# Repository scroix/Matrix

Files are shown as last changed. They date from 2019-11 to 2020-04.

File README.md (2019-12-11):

# eTextile matrix sensor / V1.0 Extension board with builtin Teensy 3.2
### Transforming textiles into an intuitive way to interact with computers
#### This project is part of an electronic textiles research on HCI gesture interaction that was started in 2005

- Author: Maurin Donneaud <maurin@etextile.org>
- Repository: https://github.com/eTextile/Matrix/tree/teensy_matrix
- Project web page: http://matrix.eTextile.org
- License: CC-BY-SA (see the License file)



## About The project
Using a fabric to sense the touch is now possible with the E256 eTextile matrix sensor.
The E256 is a development kit for designers, makers and companies who want to combine textile and programing into new eTextile projects. From the beginning this project stimulates the development of technologies in artistic use cases: playing music, combine graphics and sound, creating textile furniture that can have tactile properties, etc, etc.

This kit features 30cm by 30cm sensitive textile that allow multi-touch sensing and pressures topographic analysis.
The software, frmware and hardware are distributed under Creative Commons license (Cf: LICENSE.txt). The E256 firmware is made with Arduino IDE. BLE hardware is the next step to interface the E256-textile with mobile devices. Made out of conductive textile shaped in rows and columns and a layer of piezoresistive fabric, the E256-textile sensor is designed to be easy to make.

## Project content
- Arduino firmware : Teensy 3.1, 3.2, 4.0(TODO)
- PCB made with [KiCad](https://kicad-pcb.org/)
- eTextile matrix sensor HOWTO
- Real time 3D visualization using [openFrameworks](https://www.openframeworks.cc/)
- Audio players running on Raspberry and Bela-mini using [libPd](https://github.com/libpd)
- Same players can be lodded on PC with PureData Vanilla (http://msp.ucsd.edu/software.html)

## Publications
- [NIME17](http://www.nime2017.org/) - Designing a Multi-Touch eTextile for Music Performances.
- Maurin Donneaud, Cedric Honnet, Paul Strohmeier
  - [Paper](https://etextile.github.io/resistiveMatrix/publications/NIME17-eTextile.pdf) - [Video](https://vimeo.com/217690743)
- [MOCO17](http://moco17.movementcomputing.org/) - Music Skin: Fabric Interface for Expressive Music Control.
- Maurin Donneaud, Cedric Honnet, Paul Strohmeier
  - [Paper](https://etextile.github.io/resistiveMatrix/publications/MOCO17-MusicSkin.pdf)

## Docs
- [A video made at Schmiede 2014](http://www.kobakant.at/DIY/?p=4305/)
- [Pictures of the project and context](https://www.flickr.com/photos/maurin/albums/72157673740361510)

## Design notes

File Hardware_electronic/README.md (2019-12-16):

# eTextile matrix sensor
### Transforming textiles into an intuitive way to interact with computers
#### This project is part of an electronic textiles research on HCI gesture interaction that was started in 2005

- Author: Maurin Donneaud <maurin@etextile.org>
- Repository: https://github.com/eTextile/Matrix/tree/teensy_matrix
- Project web page: http://matrix.eTextile.org
- License: CC-BY-SA (see the License file)

### Eagle
V1.0 : the Eagle file contain a PCB with eTextile-bus solution (not available as market product)

### KiCad
V2.0 : the KiCad file contain a PCB that avoid the need of eTextile-bus

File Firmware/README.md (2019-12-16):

# E256-S / Arduino / Firmaware

### Transforming textiles into an intuitive way to interact with computers
### This project is part of an electronic textiles research on HCI gesture interaction that was started in 2005

- Author: Maurin Donneaud <maurin@etextile.org>
- Repository: https://github.com/eTextile/Matrix/tree/teensy_matrix
- Project web page: www.eTextile.org
- License: CC-BY-SA (see the License file)



## Requirements
- Programed with Arduino IDE
- This Arduino Sketch require:
 - ...

### Settings for Arduino IDE
- Board:	 Teensy_3.2 / 4.0
- USB Type:  Serial

## Program Synopsis

## Data Transmission

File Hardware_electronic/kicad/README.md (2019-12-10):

# eTextile matrix sensor
### Transforming textiles into an intuitive way to interact with computers
#### This project is part of an electronic textiles research on HCI gesture interaction that was started in 2005

- Author: Maurin Donneaud <maurin@etextile.org>
- Repository: https://github.com/eTextile/Matrix/tree/teensy_matrix
- Project web page: http://matrix.eTextile.org
- License: CC-BY-SA (see the License file)

### Eagle
This file is contanoing a PCB with eTextile bus connector - V1

### KiCad 
the textile bus systhem is not a maket productso I switch to the - V2

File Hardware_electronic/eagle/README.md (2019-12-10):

# eTextile matrix sensor / PCB

### Transforming textiles into an intuitive way to interact with computers
#### This project is part of an electronic textiles research on HCI gesture interaction that was started in 2005

- Author: Maurin Donneaud <maurin@etextile.org>
- Repository: https://github.com/eTextile/Matrix/tree/teensy_matrix
- Project web page: https://matrix.eTextile.org
- License: CC-BY-SA (see the License file)

This PCB is designed for a custom eTextile connection between a textile matrix and the Teensy_3.2 microcontroller I/O pins.

## Partslist

| Part | Value | Device | Package |
|---|:---|:---|:---|
ANALOG_INPUT  | 3.3V                         | PINHD-1X16/90           | 1X16/90              |
ANALOG_INPUT1 | 3.3V                         | PINHD-1X16              | 1X16                 |
C1            | 4.7uF                        | CAP0805                 | 0805                 |
C2            | 4.7uF                        | CAP0805                 | 0805                 |
C3            | 10uf                         | CPOL-EUE1.8-4           | E1,8-4               |
D1            | RED                          | LED1206                 | LED-1206             |
D11           | RED                          | LED1206                 | LED-1206             |
DIGITAL_OUT   |                              | PINHD-1X16/90           | 1X16/90              |
DIGITAL_OUT1  | 3.3V                         | PINHD-1X16/90           | 1X16/90              |
JP7           | LiPo Battery                 | M02-JST-2MM-SMT         | JST-2-SMD            |
R1            | 2K                           | RESISTOR0805-RES        | 0805                 |
R2            | 330                          | RESISTOR0805-RES        | 0805                 |
R3            | 330                          | RESISTOR0805-RES        | 0805                 |
RN1           | 3.3V                         | G08R                    | SIL9                 |
RN2           | 3.3V                         | G08R                    | SIL9                 |
S1            | SWITCH                       | SWITCH-SPSTSMD          | AYZ0202              |
SWITCH1       | SWITCH-MOMENTARY-2           | SWITCH-MOMENTARY-2      | TACTILE_SWITCH_TALL  |
U$1           | TEENSY_3.1_ALL_PINS_AND_PADS | TEENSY_3.1_ALL_PINS_AND_PADS | TEENSY_3.1_ALLPINS   |
U1            | MCP73831                     | MCP73831                     | SOT23-5              |
U3            |                              | AUDIO-JACKSMD2               | AUDIO-JACK-3.5MM-SMD |

## TODO

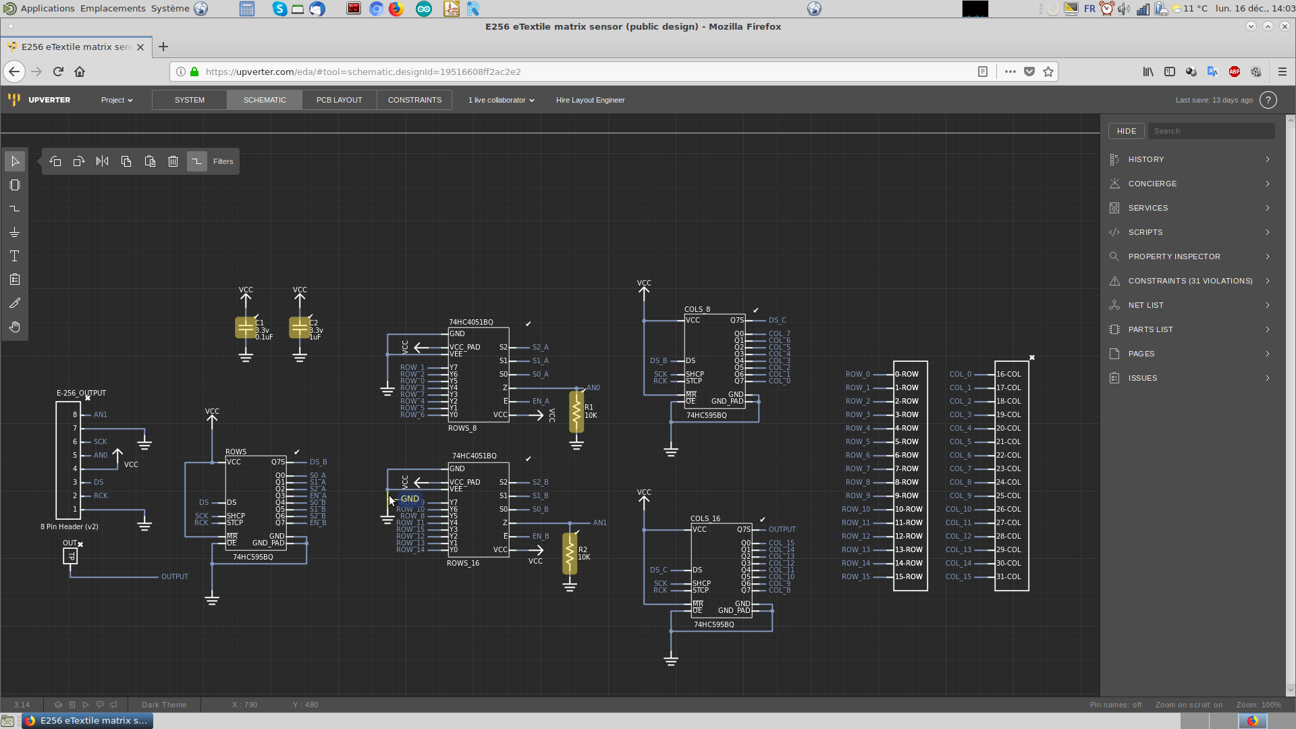
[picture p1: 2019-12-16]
Hardware_electronic/Capture du 2019-12-16 14-03-28.png

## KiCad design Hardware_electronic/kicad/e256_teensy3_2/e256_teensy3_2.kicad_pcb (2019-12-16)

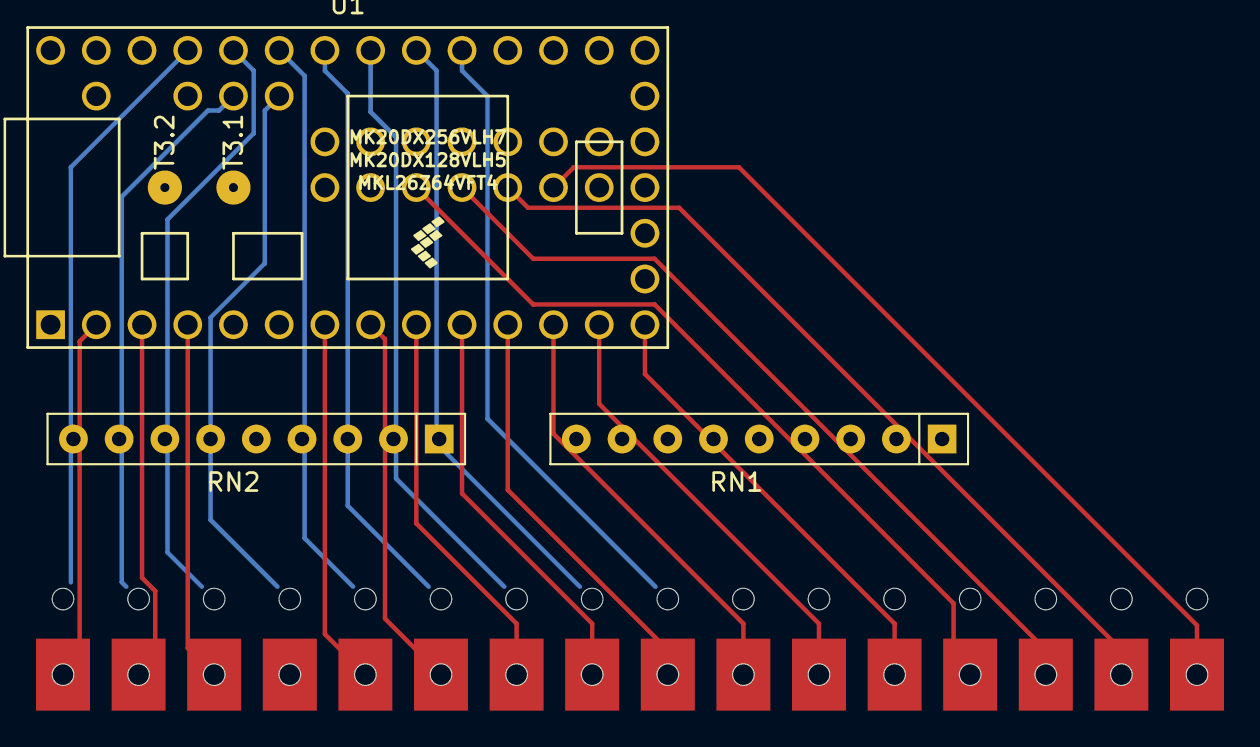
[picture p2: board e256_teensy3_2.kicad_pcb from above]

Board: 2 copper layers, 4 parts (0 on the bottom side), 31 nets.

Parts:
RN1, RN2: R_Network08_US; R_Array_SIP9
U1: Teensy3.2; Teensy30_31_32_LC
U2: e256_pad_16x16; e256_pad_16X16

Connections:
COL_0: RN1.2, U1.46, U2.16
COL_1: RN1.3, U1.47, U2.17
COL_2: RN1.4, U1.48, U2.18
COL_3: RN1.5, U1.49, U2.19
COL_4: RN1.6, U1.14, U2.20
COL_5: RN1.7, U1.13, U2.21
COL_6: RN1.8, U1.12, U2.22
COL_7: RN1.9, U1.11, U2.23
COL_8: RN2.2, U1.10, U2.24
COL_9: RN2.3, U1.9, U2.25
COL_10: RN2.4, U1.8, U2.26
COL_11: RN2.5, U1.7, U2.27
COL_12: RN2.6, U1.40, U2.28
COL_13: RN2.7, U1.4, U2.29
COL_14: RN2.8, U1.3, U2.30
COL_15: RN2.9, U1.2, U2.31
GNDREF: RN1.1, RN2.1, U1.1
ROW_0: U1.45, U2.0
ROW_1: U1.44, U2.1
ROW_2: U1.43, U2.2
ROW_3: U1.21, U2.3
ROW_4: U1.42, U2.4
ROW_5: U1.22, U2.5
ROW_6: U1.23, U2.6
ROW_7: U1.24, U2.7
ROW_10: U1.27, U2.10
ROW_11: U1.28, U2.11
ROW_12: U1.37, U2.12
ROW_13: U1.29, U2.13
ROW_14: U1.36, U2.14
ROW_15: U1.30, U2.15

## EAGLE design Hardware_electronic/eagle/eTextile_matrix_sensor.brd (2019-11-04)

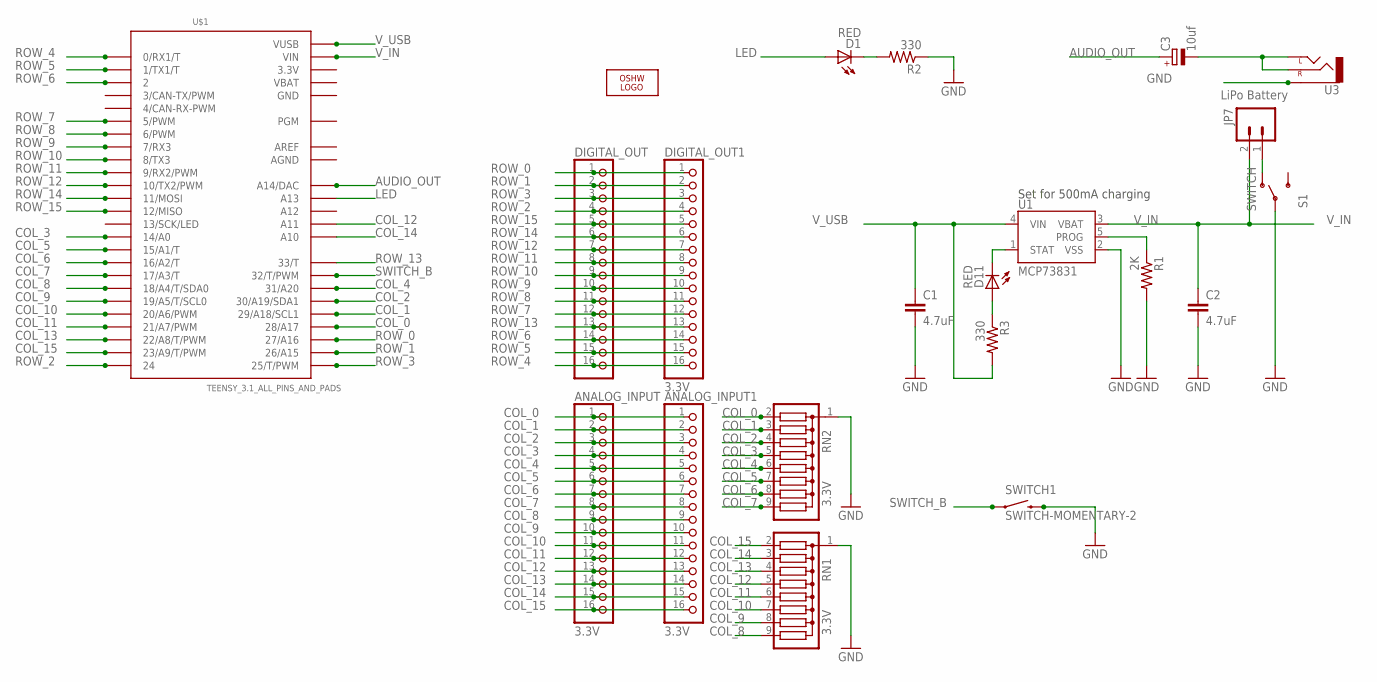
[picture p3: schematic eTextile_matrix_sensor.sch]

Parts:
ANALOG_INPUT: 3.3V; 1X16/90
ANALOG_INPUT1: 3.3V; 1X16
C1, C2: 4.7uF; 0805
C3: 10uf; E1,8-4
D1, D11: RED; LED-1206
DIGITAL_OUT: PINHD-1X16/90; 1X16/90
DIGITAL_OUT1: 3.3V; 1X16/90
JP7: LiPo Battery; JST-2-SMD
LOGO1: OSHW_LOGO_8MILX0350-NT; OSHW_8X350_NOTEXT
R1: 2K; 0805
R2, R3: 330; 0805
RN1, RN2: 3.3V; SIL9
S1: SWITCH; AYZ0202
SWITCH1: SWITCH-MOMENTARY-2; TACTILE_SWITCH_TALL
U1: MCP73831; SOT23-5
U3: AUDIO-JACKSMD2; AUDIO-JACK-3.5MM-SMD
U$1: TEENSY_3.1_ALL_PINS_AND_PADS; TEENSY_3.1_ALLPINS

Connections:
3.3V: U$1.3.3V, U$1.3.3V1 (3.3V), U$1.3.3V2 (3.3V)
AGND: U$1.AGND
AREF: U$1.AREF
AUDIO_OUT: C3.+, U$1.A14 (A14/DAC)
COL_0: ANALOG_INPUT.1, ANALOG_INPUT1.1, RN2.2, U$1.28 (28/A17)
COL_1: ANALOG_INPUT.2, ANALOG_INPUT1.2, RN2.3, U$1.29 (29/A18/SCL1)
COL_2: ANALOG_INPUT.3, ANALOG_INPUT1.3, RN2.4, U$1.30 (30/A19/SDA1)
COL_3: ANALOG_INPUT.4, ANALOG_INPUT1.4, RN2.5, U$1.14/A0
COL_4: ANALOG_INPUT.5, ANALOG_INPUT1.5, RN2.6, U$1.31 (31/A20)
COL_5: ANALOG_INPUT.6, ANALOG_INPUT1.6, RN2.7, U$1.15/A1 (15/A1/T)
COL_6: ANALOG_INPUT.7, ANALOG_INPUT1.7, RN2.8, U$1.16/A2 (16/A2/T)
COL_7: ANALOG_INPUT.8, ANALOG_INPUT1.8, RN2.9, U$1.17/A3 (17/A3/T)
COL_8: ANALOG_INPUT.9, ANALOG_INPUT1.9, RN1.9, U$1.18/A4 (18/A4/T/SDA0)
COL_9: ANALOG_INPUT.10, ANALOG_INPUT1.10, RN1.8, U$1.19/A5 (19/A5/T/SCL0)
COL_10: ANALOG_INPUT.11, ANALOG_INPUT1.11, RN1.7, U$1.20/A6 (20/A6/PWM)
COL_11: ANALOG_INPUT.12, ANALOG_INPUT1.12, RN1.6, U$1.21/A7 (21/A7/PWM)
COL_12: ANALOG_INPUT.13, ANALOG_INPUT1.13, RN1.5, U$1.A11
COL_13: ANALOG_INPUT.14, ANALOG_INPUT1.14, RN1.4, U$1.22/A8 (22/A8/T/PWM)
COL_14: ANALOG_INPUT.15, ANALOG_INPUT1.15, RN1.3, U$1.A10
COL_15: ANALOG_INPUT.16, ANALOG_INPUT1.16, RN1.2, U$1.23/A9 (23/A9/T/PWM)
GND: C1.2, C2.2, R1.2, R2.1, RN1.1, RN2.1, S1.2, SWITCH1.B2 (2), U1.2 (VSS), U3.SLEEVE, U$1.GND, U$1.GND1 (GND), U$1.GND2 (GND)
LED: D1.A, U$1.A13
unnamed: C3.-, U3.RING (RIGHT), U3.TIP (LEFT)
unnamed: D11.A, R3.1
unnamed: JP7.1, S1.1 (O)
unnamed: D1.C, R2.2
PROG: R1.1, U1.5 (PROG)
ROW_0: DIGITAL_OUT.1, DIGITAL_OUT1.1, U$1.27 (27/A16)
ROW_1: DIGITAL_OUT.2, DIGITAL_OUT1.2, U$1.26 (26/A15)
ROW_2: DIGITAL_OUT.4, DIGITAL_OUT1.4, U$1.24
ROW_3: DIGITAL_OUT.3, DIGITAL_OUT1.3, U$1.25 (25/T/PWM)
ROW_4: DIGITAL_OUT.16, DIGITAL_OUT1.16, U$1.0 (0/RX1/T)
ROW_5: DIGITAL_OUT.15, DIGITAL_OUT1.15, U$1.1 (1/TX1/T)
ROW_6: DIGITAL_OUT.14, DIGITAL_OUT1.14, U$1.2
ROW_7: DIGITAL_OUT.12, DIGITAL_OUT1.12, U$1.5 (5/PWM)
ROW_8: DIGITAL_OUT.11, DIGITAL_OUT1.11, U$1.6 (6/PWM)
ROW_9: DIGITAL_OUT.10, DIGITAL_OUT1.10, U$1.7 (7/RX3)
ROW_10: DIGITAL_OUT.9, DIGITAL_OUT1.9, U$1.8 (8/TX3)
ROW_11: DIGITAL_OUT.8, DIGITAL_OUT1.8, U$1.9 (9/RX2/PWM)
ROW_12: DIGITAL_OUT.7, DIGITAL_OUT1.7, U$1.10 (10/TX2/PWM)
ROW_13: DIGITAL_OUT.13, DIGITAL_OUT1.13, U$1.33 (33/T)
ROW_14: DIGITAL_OUT.6, DIGITAL_OUT1.6, U$1.11 (11/MOSI)
ROW_15: DIGITAL_OUT.5, DIGITAL_OUT1.5, U$1.12 (12/MISO)
STAT: D11.C, U1.1 (STAT)
SWITCH_B: SWITCH1.A2 (1), U$1.32 (32/T/PWM)
VBAT: U$1.VBAT
V_IN: C2.1, JP7.2, U1.3 (VBAT), U$1.VIN
V_USB: C1.1, R3.2, U1.4 (VIN), U$1.VUSB

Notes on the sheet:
Set for 500mA charging

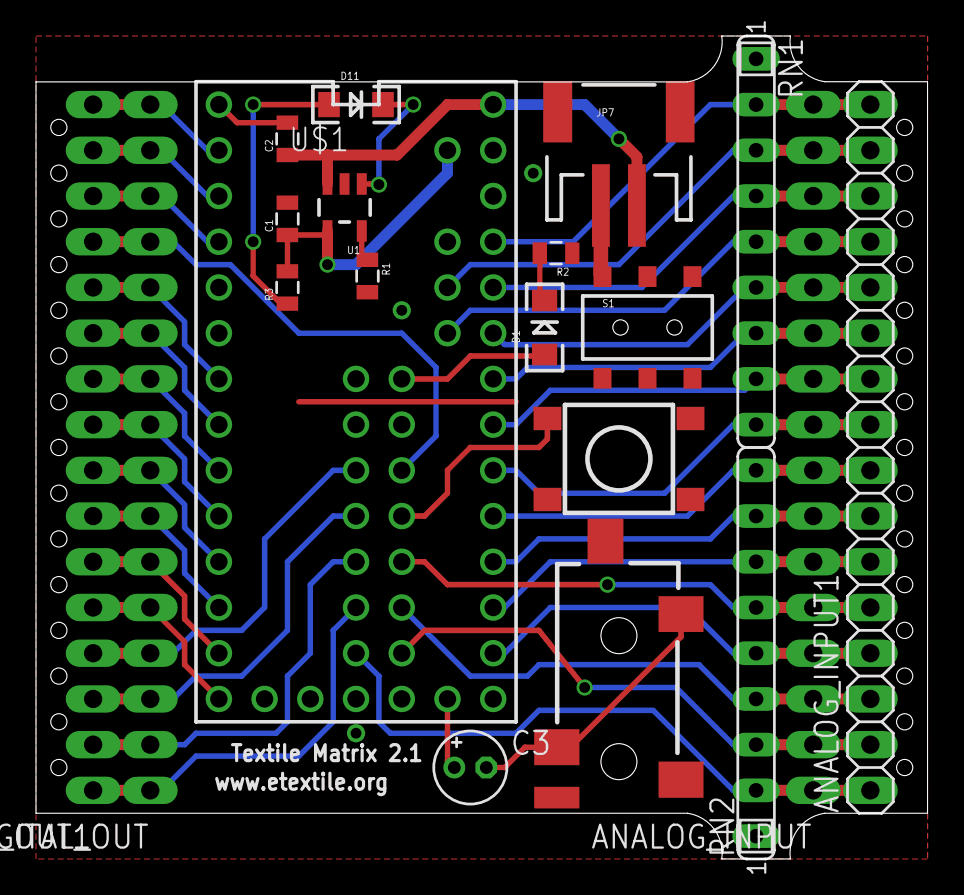
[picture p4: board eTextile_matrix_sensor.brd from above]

Board: 2 copper layers, 49.5 x 45.7 mm, 21 parts (0 on the bottom side), 45 nets.

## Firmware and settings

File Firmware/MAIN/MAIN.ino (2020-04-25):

/*
  ** E256 Firmware v1.1 **
  This file is part of the eTextile-matrix-sensor project - http://matrix.eTextile.org
  Copyright (c) 2014- Maurin Donneaud <maurin@etextile.org>
  This work is licensed under Creative Commons Attribution-ShareAlike 4.0 International license, see the LICENSE file for details.
*/

// FPS with CPU speed to 120 MHz (Overclock)
// Optimize Fastest with LTO (Link Time Optimizations)
//   523 FPS : ADC_INPUT
//    .. FPS : ADC_INPUT / BLOB_TRACKING
//    .. FPS : ADC_INPUT / BILINEAR_INTERPOLATION
//    39 FPS : ADC_INPUT / BILINEAR_INTERPOLATION / BLOB_TRACKING

#include <SPI.h>        // https://www.pjrc.com/teensy/td_libs_SPI.html
#include <ADC.h>        // https://github.com/pedvide/ADC
#include <MIDI.h>       // http://www.pjrc.com/teensy/td_midi.html

#include "config.h"
#include "interp.h"
#include "blob.h"

SPISettings settings(16000000, MSBFIRST, SPI_MODE0);

ADC *adc = new ADC();     // ADC object
ADC::Sync_result result;  // ADC_0 & ADC_1

// Array to store all parameters used to configure the two 8:1 analog multiplexeurs
// Eatch byte |ENA|A|B|C|ENA|A|B|C|
const byte setDualRows[RAW_ROWS] = {
  0x55, 0x77, 0x66, 0x44, 0x22, 0x11, 0x00, 0x33
};

uint8_t minValsArray[RAW_FRAME] = {0};            // 1D Array to store smallest values
uint8_t frameArray[RAW_FRAME] = {0};              // 1D Array to store ofseted analog input values

uint8_t bitmapArray[NEW_FRAME] = {0};             // 1D Array to store binary values (16*16) array containing (64*64) values
uint8_t interpFrameArray[NEW_FRAME] = {0};        // 1D Array to store bilinear interpolated values

xylr_t lifoArray[LIFO_MAX_NODES] = {0};           // 1D Array to store lifo nodes
blob_t blobArray[MAX_NODES] = {0};                // 1D Array to store blobs

uint8_t blobPacket[BLOB_PACKET_SIZE] = {0};       // 1D Array to store blobs in OSC format

image_t  inputFrame;         // Input frame values
interp_t interp;             //
image_t  interpolatedFrame;  //
image_t  bitmap;             // Used by Scanline Flood Fill algorithm / SFF
lifo_t   lifo_stack;         // Lifo free nodes stack
lifo_t   lifo;               // Lifo stack
llist_t  blobs_stack;        // Blobs free nodes linked list
llist_t  blobs;              // Intermediate blobs linked list
llist_t  outputBlobs;        // Output blobs linked list

uint8_t threshold = 20;
uint8_t calibration_cycles = 20;
boolean calibrate = true;

void setup() {

  //pinMode(LED_BUILTIN, OUTPUT);   // FIXME - BUILTIN_LED is used for SPI hardware
  //digitalWrite(LED_BUILTIN, LOW); // FIXME - BUILTIN_LED is used for SPI hardware

  //pinMode(BUTTON_PIN, INPUT_PULLUP);          // Set button pin as input and activate the input pullup resistor // FIXME - NO BUTTON_PIN ON the E256!
  //attachInterrupt(BUTTON_PIN, calib, RISING); // Attach interrrupt on button PIN // FIXME - NO BUTTON_PIN ON the E256

  SPI_SETUP();

  ADC_SETUP();

  INTERP_SETUP(
    &inputFrame,          // image_t*
    &frameArray[0],       // uint8_t*
    &interpolatedFrame,   // image_t*
    &interpFrameArray[0], // uint8_t*
    &interp               // interp_t*
  );

  BLOB_SETUP(
    &inputFrame,          // image_t*
    &bitmap,              // image_t*
    &bitmapArray[0],      // uint8_t*
    &lifo,                // lifo_t*
    &lifo_stack,          // lifo_t*
    &lifoArray[0],        // xylr_t*
    &blobs,               // list_t*
    &blobs_stack,         // list_t*
    &blobArray[0],        // blob_t*
    &outputBlobs          // list_t*
  );
  usbMIDI.begin();
}

//////////////////// LOOP
void loop() {

  matrix_blobs_get();

  while (usbMIDI.read()); // Read and discard any incoming MIDI messages

#ifdef DEBUG_ADC
  matrix_scan(&frameArray[0]);

  for (uint8_t col = 0; col < RAW_COLS; col++) {
    for (uint8_t row = 0; row < RAW_ROWS; row++) {
      uint8_t index = col * RAW_COLS + row;          // Compute 1D array index
      Serial.printf("\t%d", frameArray[index]);
    }
    Serial.println();
  }
  Serial.println();
  delay(50);
#endif /*__DEBUG_ADC__*/

#ifdef DEBUG_INTERP
  if (calibrate) matrix_calibrate(&minValsArray[0]);
  matrix_scan(&frameArray[0]);
  matrix_interp(&interpolatedFrame, &inputFrame, &interp);
  for (uint8_t col = 0; col < NEW_COLS; col++) {
    for (uint8_t row = 0; row < NEW_ROWS; row++) {
      uint16_t index = col * NEW_COLS + row;          // Compute 1D array index
      Serial.printf("-%d", interpFrameArray[index]);
    }
    Serial.println();
  }
  Serial.println();
  delay(50);
#endif /*__DEBUG_INTERP__*/

#ifdef DEBUG_BITMAP
  if (calibrate) matrix_calibrate(&minValsArray[0]);
  matrix_scan(&frameArray[0]);
  matrix_interp(&interpolatedFrame, &inputFrame, &interp);
  find_blobs(
    threshold,          // uint8_t
    &interpolatedFrame, // image_t (uint8_t array[NEW_FRAME] - 64*64 1D array)
    &bitmap,            // image_t (uint8_t array[NEW_FRAME] - 64*64 1D array)
    &lifo_stack,        // lifo_t
    &lifo,              // lifo_t
    &blobs_stack,       // list_t
    &blobs,             // list_t
    &outputBlobs        // list_t
  );

  for (uint8_t posY = 0; posY < NEW_COLS; posY++) {
    uint8_t* bmp_row = COMPUTE_BINARY_IMAGE_ROW_PTR (&bitmap, posY);
    for (uint8_t posX = 0; posX < NEW_ROWS; posX++) {
      Serial.print(IMAGE_GET_BINARY_PIXEL_FAST(bmp_row, posX));
    }
    Serial.println();
  }
  Serial.println();
  delay(50);
#endif /*__DEBUG_BITMAP__*/

#ifdef DEBUG_BLOBS_OSC
  if (calibrate) matrix_calibrate(&minValsArray[0]);
  matrix_scan(&frameArray[0]);
  matrix_interp(&interpolatedFrame, &inputFrame, &interp);
  find_blobs(
    threshold,          // uint8_t
    &interpolatedFrame, // image_t (uint8_t array[NEW_FRAME] - 64*64 1D array)
    &bitmap,            // image_t (uint8_t array[NEW_FRAME] - 64*64 1D array)
    &lifo_stack,        // lifo_t
    &lifo,              // lifo_t
    &blobs_stack,       // list_t
    &blobs,             // list_t
    &outputBlobs        // list_t
  );

  for (blob_t* blob = ITERATOR_START_FROM_HEAD(&outputBlobs); blob != NULL; blob = ITERATOR_NEXT(blob)) {
    Serial.print (blob->UID);        // uint8_t unique session ID
    Serial.print(" ");
    Serial.print (blob->alive);      // uint8_t
    Serial.print(" ");
    Serial.print (blob->centroid.X); // int8_t
    Serial.print(" ");
    Serial.print (blob->centroid.Y); // int8_t
    Serial.print(" ");
    Serial.print (blob->box.W);      // uint8_t
    Serial.print(" ");
    Serial.print (blob->box.H);      // uint8_t
    Serial.print(" ");
    Serial.print (blob->box.D);      // uint8_t
    Serial.println();
  }
#endif /*__DEBUG_BLOBS_OSC__*/
}

//////////////////////////////////////////////////// FONCTIONS

void SPI_SETUP(void) {

  //SPI.setSCK(E256_SS_PIN);        // D10 - Hardware SPI no need to specify it!
  //SPI.setSCK(E256_SCK_PIN);       // D13 - Hardware SPI no need to specify it!
  //SPI.setMOSI(E256_MOSI_PIN);     // D11 - Hardware SPI no need to specify it!
  pinMode(E256_SS_PIN, OUTPUT);
  pinMode(E256_SCK_PIN, OUTPUT);
  pinMode(E256_MOSI_PIN, OUTPUT);
  digitalWriteFast(E256_SS_PIN, LOW);    // Set latchPin LOW
  digitalWriteFast(E256_SS_PIN, HIGH);   // Set latchPin HIGH
  SPI.begin();                           // Start the SPI module
  SPI.beginTransaction(settings);        // (16000000, MSBFIRST, SPI_MODE0);
}

void ADC_SETUP(void) {

  pinMode(ADC0_PIN, INPUT);              // Teensy PIN A9
  pinMode(ADC1_PIN, INPUT);              // Teensy PIN A3

  adc->adc0->setAveraging(1);                                           // Set number of averages
  adc->adc0->setResolution(8);                                          // Set bits of resolution
  adc->adc0->setConversionSpeed(ADC_CONVERSION_SPEED::VERY_HIGH_SPEED); // Change the conversion speed
  //adc->adc0->setConversionSpeed(ADC_CONVERSION_SPEED::HIGH_SPEED);    // Change the conversion speed
  adc->adc0->setSamplingSpeed(ADC_SAMPLING_SPEED::VERY_HIGH_SPEED);     // Change the sampling speed
  //adc->adc0->setSamplingSpeed(ADC_SAMPLING_SPEED::HIGH_SPEED);        // Change the sampling speed
  //adc->adc0->enableCompare(1.0 / 3.3 * adc->adc0->getMaxValue(), 0);  // Measurement will be ready if value < 1.0V

  adc->adc1->setAveraging(1);                                           // Set number of averages
  adc->adc1->setResolution(8);                                          // Set bits of resolution
  adc->adc1->setConversionSpeed(ADC_CONVERSION_SPEED::VERY_HIGH_SPEED); // Change the conversion speed
  // adc->adc1->setConversionSpeed(ADC_CONVERSION_SPEED::HIGH_SPEED);   // Change the conversion speed
  adc->adc1->setSamplingSpeed(ADC_SAMPLING_SPEED::VERY_HIGH_SPEED);     // Change the sampling speed
  //adc->adc1->setSamplingSpeed(ADC_SAMPLING_SPEED::HIGH_SPEED);        // Change the sampling speed
  //adc->adc1->enableCompare(1.0 / 3.3 * adc->adc1->getMaxValue(), 0);  // Measurement will be ready if value < 1.0V
}

// Columns are digital OUTPUT PINS - We supply them one by one sequentially
// Rows are analog INPUT PINS - We sens them two by two
void matrix_scan(uint8_t* outputFrame) {

  uint32_t setCols = 0x10000;

  for (uint8_t col = 0; col < RAW_COLS; col++) {    // 0 to 15
    setCols = setCols >> 1;
    for (uint8_t row = 0; row < DUAL_ROWS; row++) { // 0 to 7

      digitalWriteFast(E256_SS_PIN, LOW);   // Set latchPin LOW
      SPI.transfer(setCols & 0xFF);         // Shift out the LSB byte to set up the OUTPUT shift register
      SPI.transfer((setCols >> 8) & 0xFF);  // Shift out the MSB byte to set up the OUTPUT shift register
      SPI.transfer(setDualRows[row]);       // Shift out one byte that setup the two 8:1 analog multiplexers
      digitalWriteFast(E256_SS_PIN, HIGH);  // Set latchPin HIGH
      //delayMicroseconds(5);               // TODO: see switching time of the 74HC4051BQ multiplexeur

      uint8_t rowIndexA = row * RAW_COLS + col; // Row IndexA computation
      uint8_t rowIndexB = rowIndexA + 128;      // Row IndexB computation (ROW_FRAME/2 == 128)

      result = adc->analogSynchronizedRead(ADC0_PIN, ADC1_PIN);

      int valA = result.result_adc0 - minValsArray[rowIndexA];
      valA > 0 ? outputFrame[rowIndexA] = (uint8_t)valA : outputFrame[rowIndexA] = 0;
      int valB = result.result_adc1 - minValsArray[rowIndexB];
      valB > 0 ? outputFrame[rowIndexB] = (uint8_t)valB : outputFrame[rowIndexB] = 0;
    }
  }
}

void matrix_calibration_set() {
  calibrate = true;
}

// Columns are digital OUTPUT PINS - We supply them one by one sequentially
// Rows are analog INPUT PINS - We sens them two by two
void matrix_calibrate(uint8_t* outputFrame) {

  for (uint8_t i = 0; i < calibration_cycles; i++) {

    uint32_t setCols = 0x10000;

    for (uint8_t col = 0; col < RAW_COLS; col++) {
      setCols = setCols >> 1;
      for (uint8_t row = 0; row < DUAL_ROWS; row++) {

        digitalWriteFast(E256_SS_PIN, LOW);   // Set latchPin LOW
        SPI.transfer(setCols & 0xFF);         // Shift out the LSB byte to set up the OUTPUT shift register
        SPI.transfer((setCols >> 8) & 0xFF);  // Shift out the MSB byte to set up the OUTPUT shift register
        SPI.transfer(setDualRows[row]);       // Shift out one byte that setup the two 8:1 analog multiplexers
        digitalWriteFast(E256_SS_PIN, HIGH);  // Set latchPin HIGH
        //delayMicroseconds(5);                 // TODO: See switching time of the 74HC4051BQ multiplexeur

        result = adc->analogSynchronizedRead(ADC0_PIN, ADC1_PIN);
        uint8_t ADC0_val = result.result_adc0;
        uint8_t ADC1_val = result.result_adc1;

        uint8_t rowIndexA = row * RAW_COLS + col; // Row IndexA computation
        uint8_t rowIndexB = rowIndexA + 128;      // Row IndexB computation (ROW_FRAME/2 == 128)

        if (ADC0_val > outputFrame[rowIndexA]) outputFrame[rowIndexA] = ADC0_val;
        if (ADC1_val > outputFrame[rowIndexB]) outputFrame[rowIndexB] = ADC1_val;
      }
    }
  }
  calibrate = false;
}

// Set the threshold
void matrix_threshold_set() {
  //threshold = msg.getInt(0) & 0xFF; // Get the first uint8_t of the int32_t
}

void matrix_blobs_get() {

  if (calibrate) matrix_calibrate(&minValsArray[0]);
  matrix_scan(&frameArray[0]);
  matrix_interp(&interpolatedFrame, &inputFrame, &interp);
  find_blobs(
    threshold,          // uint8_t
    &interpolatedFrame, // image_t (uint8_t array[NEW_FRAME] - 64*64 1D array)
    &bitmap,            // image_t (uint8_t array[NEW_FRAME] - 64*64 1D array)
    &lifo_stack,        // lifo_t
    &lifo,              // lifo_t
    &blobs_stack,       // list_t
    &blobs,             // list_t
    &outputBlobs        // list_t
  );

  // Send all blobs in MIDI format
  // usbMIDI.sendControlChange(control, value, channel);
  int pos = 0;
  for (blob_t* blob = ITERATOR_START_FROM_HEAD(&outputBlobs); blob != NULL; blob = ITERATOR_NEXT(blob)) {

    pos = blob->UID * 10;
    
    if (blob->alive == 1) {
      //usbMIDI.sendControlChange(1 + pos, blob->UID,      1); //
      usbMIDI.sendControlChange(0 + pos, blob->alive,      1); //
      usbMIDI.sendControlChange(1 + pos, blob->centroid.X, 1); //
      usbMIDI.sendControlChange(2 + pos, blob->centroid.Y, 1); //
      usbMIDI.sendControlChange(3 + pos, blob->box.W,      1); //
      usbMIDI.sendControlChange(4 + pos, blob->box.H,      1); //
      usbMIDI.sendControlChange(5 + pos, blob->box.D >> 1, 1); //
    }
    else {
      //usbMIDI.sendControlChange(1 + pos, 0, 1); //
      usbMIDI.sendControlChange(0 + pos, 0, 1);   //
      usbMIDI.sendControlChange(1 + pos, 0, 1);   //
      usbMIDI.sendControlChange(2 + pos, 0, 1);   //
      usbMIDI.sendControlChange(3 + pos, 0, 1);   //
      usbMIDI.sendControlChange(4 + pos, 0, 1);   //
      usbMIDI.sendControlChange(5 + pos, 0, 1);   //
    }
  }
}

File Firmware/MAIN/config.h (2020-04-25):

/*
  This file is part of the eTextile-matrix-sensor project - http://matrix.eTextile.org
  Copyright (c) 2014- Maurin Donneaud <maurin@etextile.org>thun
  This work is licensed under Creative Commons Attribution-ShareAlike 4.0 International license, see the LICENSE file for details.
*/

#ifndef __CONFIG_H__
#define __CONFIG_H__

#include <Arduino.h>

/* __E256 BOARD CONTROL__*/

//#define E256_X0 -1        // TODO: select X-axis origine [-1:1]
//#define E256_Y0 -1        // TODO: select Y-axis origine [-1:1]

#define E256_MIDI

//#define DEBUG_ADC
//#define DEBUG_INTERP
//#define DEBUG_BITMAP
//#define DEBUG_BLOBS_ID
//#define DEBUG_BLOBS_OSC
//#define DEBUG_FPS

//#define LED_BUILTIN         13        // FIXME - SPI (hardware) conflict
//#define BUTTON_PIN          32        // FIXME - NO BUTTON_PIN on the E256

//#define BAUD_RATE           115200
//#define BAUD_RATE           230400
#define RAW_COLS              16
#define RAW_ROWS              16
#define DUAL_ROWS             (RAW_ROWS / 2)
#define SCALE_X               4
#define SCALE_Y               4
#define RAW_FRAME             (RAW_COLS * RAW_ROWS)
#define NEW_COLS              (RAW_COLS * SCALE_X)
#define NEW_ROWS              (RAW_ROWS * SCALE_Y)
#define NEW_FRAME             (NEW_COLS * NEW_ROWS)
#define MAX_NODES             40       // Set the maximum nodes number
#define LIFO_MAX_NODES        127      // Set the maximum nodes number
#define X_STRIDE              4
#define Y_STRIDE              1
#define MIN_BLOB_PIX          16       // Set the minimum blob pixels
#define MAX_BLOB_PIX          4095     // Set the maximum blob pixels
#define BLOB_PACKET_SIZE      7        // Blob data packet (bytes)

#define E256_SS_PIN           10       // SPI:SS    E2B56:RCK  // D10 - Hardware SPI no need to specify it
#define E256_SCK_PIN          13       // SPI:SCK   E2B56:SCK  // D13 - Hardware SPI no need to specify it
#define E256_MOSI_PIN         11       // SPI:MOSI  E2B56:DS   // D11 - Hardware SPI no need to specify it

#define ADC0_PIN              A9       // The output of multiplexerA (SIG pin) is connected to Analog pin 9
#define ADC1_PIN              A3       // The output of multiplexerB (SIG pin) is connected to Analog pin 3

#endif /*__CONFIG_H__*/

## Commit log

2018-05-18 Added Firmware/MAIN/build-teensy31/
2019-11-04 Removed old version (without blob detection)
    [eTextile_matrix_sensor.brd, eTextile_matrix_sensor.sch]
2019-11-04 Added new file - still need to rebuild PCB with new eTextile connector
    [eTextile_matrix_sensor.brd, eTextile_matrix_sensor.sch]
2019-11-04 Updated OpenFrameworks to work with new Arduino Firmware
2019-12-03 Renaming file
    [eTextile_matrix_sensor.brd, eTextile_matrix_sensor.sch]
2019-12-03 Removed bad file
    [eTextile_matrix_sensor.brd, eTextile_matrix_sensor.sch]
2019-12-05 Updated for new pcb design
2019-12-07 Adde pins under PCB to the Teensy lib
    [E256_teensy3_2.kicad_pcb, E256_teensy3_2.sch]
2019-12-08 Updated path
    [E256_teensy3_2.kicad_pcb, E256_teensy3_2.sch]
2019-12-10 Added V1.2 version - working prototype
2019-12-10 Added new README file for the electronic hardware PCBs
2019-12-11 Updated for new E256 pcb
2019-12-16 Added kicad local ath def
2019-12-16 Removed submodules
    [E256_teensy3_2.kicad_pcb, E256_teensy3_2.sch, e256_teensy3_2.kicad_pcb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]
2019-12-17 Set ADC to 8bit
2020-04-25 Added device name E256
2020-04-25 Removed OSC driver

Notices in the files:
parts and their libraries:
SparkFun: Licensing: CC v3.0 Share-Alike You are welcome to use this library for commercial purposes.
